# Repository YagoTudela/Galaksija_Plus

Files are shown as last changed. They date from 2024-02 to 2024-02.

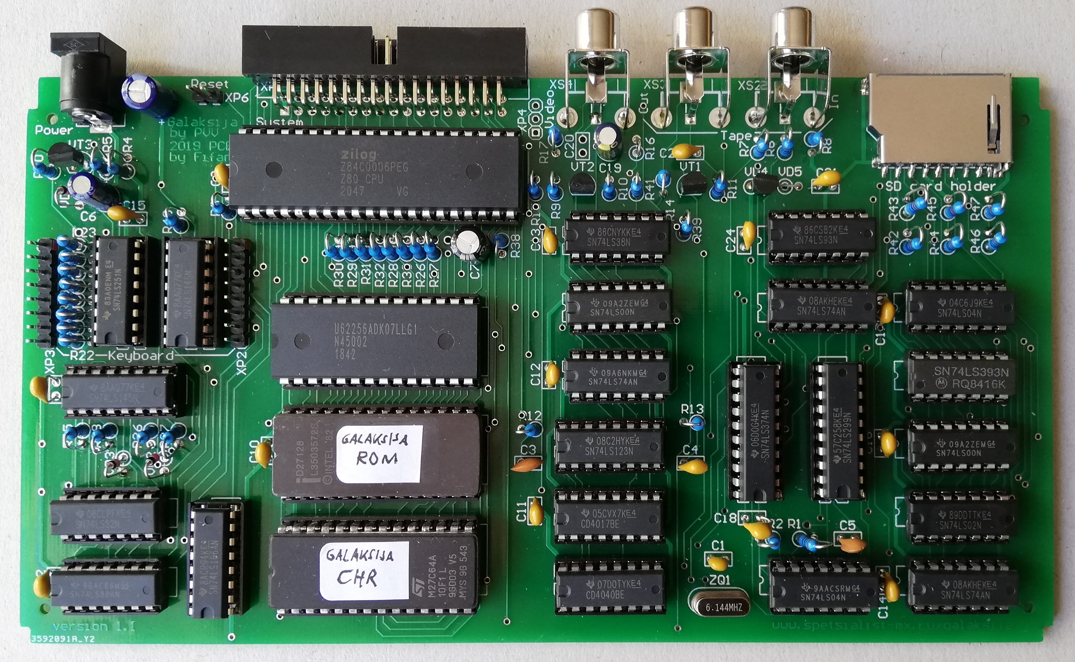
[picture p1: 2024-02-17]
GalaksijaPlusClone_BoardComplete_RetroBertie.jpg

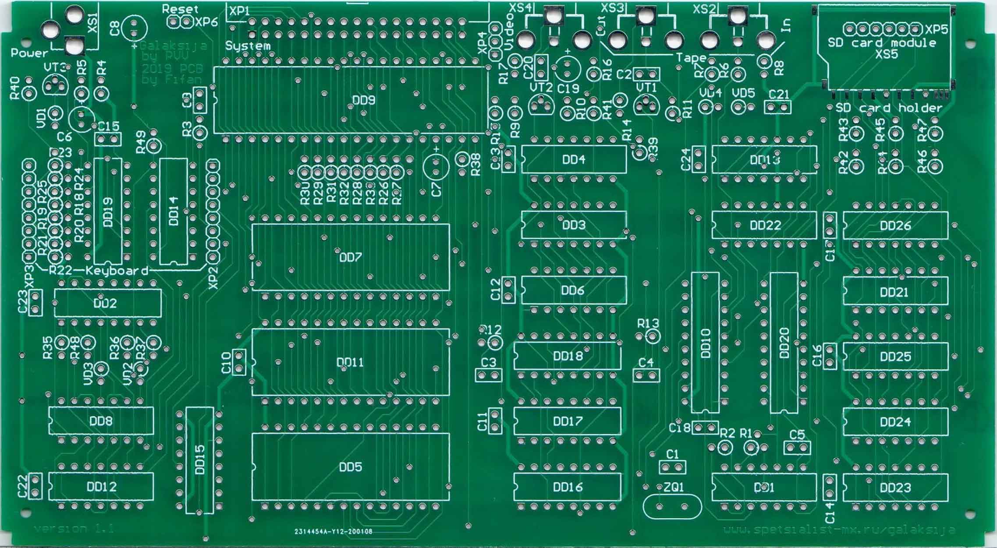
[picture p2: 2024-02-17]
GalaksijaPlusClone_BoardEmpty_YT2FSG.jpg

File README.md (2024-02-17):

# Galaksija_Plus
 GalaksijaPlus

Galaksija Plus Replica by Fifan/PVV: Assembly Guide 
by RobertK a.k.a. Retro Bertie (2022)
RetroBertie@outlook.com

https://drive.google.com/drive/folders/1J3synVV-5PiKcZs9oFsY-6CqWDRKv7X2

This is a replica of the Z80-based "Galaskija Plus" DIY computer from Yugoslavia from the 1980s.

The original files had been published on...

http://www.spetsialist-mx.ru/Galaksija/index6.html

...but this web site is no longer available, so I have put all the files online here and added a BOM, and the Gerber and Sprint Layout files for my PS/2 keyboard adapter PCB.

GalaksijaPlus_Fifan_Schematic.pdf			Scheme of Galaksija Plus clone from Fifan
galaksija_chrgen.rar					Binary file for EPROM 27C64 "CHRGEN" (DD5)
galaksija_rom_v8_6.zip					Binary file for EPROM 27C128 "ROM" (DD11)
GalaksijaPlusGerbers.rar				Gerber files for the production of PCB
PVVSDcard.rar						File archive for SD card from PVV
PVVPS2adapter.zip					File archive for PS/2 keyboard adapter from PVV
GalaksijaPlus_PVV_BOM.xls				BOM for the main board, PS/2 adapter and Sound Generator (Retro Bertie)
GalaksijaPlusClone_BoardComplete_RetroBertie.jpg	Photo of the complete board (Retro Bertie)
GalaksijaPlusClone_BoardEmpty_YT2FSG.jpg		Photo of the empty board (YT2FSG)

For writing the 27C64 EPROM DD5 ("CHRGEN"), use the file GALAXY_CHRGENP8.BIN (8K).
For the 27C128 EPROM DD11 ("ROM") use GALAXY_ROM16.BIN (16K).

The following modifications should be done (they are already included in the BOM):

1. Video Output
Video Components are: VT2, R16, R17, C19, C20
R16 = 0 (connect directly)
R17 = 220R
C19 = 4.7uF
Do not mount C20

2. SD Card
Instead of VD4 and VD5, use a 78L33 (3.3V) voltage stabilizer
Left Pin = Input, Centre Pin = GND, Right pin = Output

3. Power Supply for the Main Board
It is recommended to use a laboratory PSU, start at 5V and reduce the voltage until the picture gets stable.
The picture should get stable when the voltage is reduced to 4.35 Volts.
If you don't have a laboratory PSU, you can use a 5V mobile phone charger, reduce the voltage using a 1N4007 diode. If the resulting voltage should be too low, use two Schottky diodes (e.g. 1N5817 or 1N5819) instead.
Connect XP2 Pin 1 (the rightmost pin) with DD14 Pin 8 (GND), this will connect ground between the main board and the PS/2 adapter. With this modification, the keyboard will work with separate power supplies too.

4. The correct values for the resistors R11 and R14 are:
R11 100
R14 2,4K
In the schematic, their values are swapped, with the result that loading from the audio input would not work.

Here is a Youtube video showing my building process:
https://youtu.be/Uxc2ua1hdcY

=== SOURCES / REFERENCES ===

http://www.spetsialist-mx.ru/Galaksija/
The repository for the main board Gerber files, ROM images and Schematic. Now offline, an archived version can be accessed here:
https://web.archive.org/web/20210123223417/http://www.spetsialist-mx.ru/Galaksija/index6.html

http://emulator.galaksija.org/MagScans/index.html
The magazine scans shown in the beginning of my video were downloaded from there.

https://www.youtube.com/watch?v=NPDcvZwGBMA&t=24s
Youtube video "Voja Antonic o igrama na Galaksiji", the photo of Mr. Antonic was taken from there.

https://www.qsl.net/yt2fsg/galaksija/galaksija_clone.html
Goran's Galaksija Clone, the photo of the empty board was taken from there.

=== OTHER LINKS ===

http://retrospec.sgn.net/users/tomcat/yu/Galaksija_list.php
Software Archive

http://galaksija.epizy.com/Help/Tape/
Another software Archive on galaksija.epizy.com

https://github.com/z88dk/z88dk/wiki/Platform---Galaksija
z88dk C compiler supporting the Galaksija system (among many other machines)

https://blog.vladovince.com/building-a-galaksija-the-1980s-yugoslav-8-bit-microcomputer-part-i-the-tech/
https://github.com/mejs/galaksija
Building the original Galaksija computer

https://oldcomputer.info/8bit/galaksija/index.htm
Another person who has built the original Galaksija

https://www.apuliaretrocomputing.it/wordpress/?p=4234
One more original Galaksija built

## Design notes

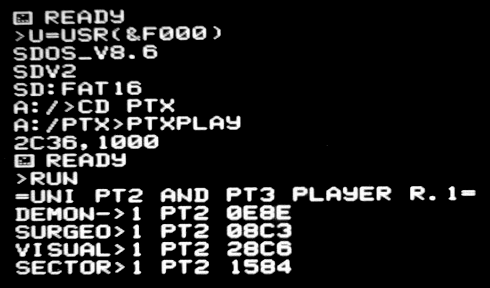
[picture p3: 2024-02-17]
SoundGenerator/SoundGeneratorPVV_03.png

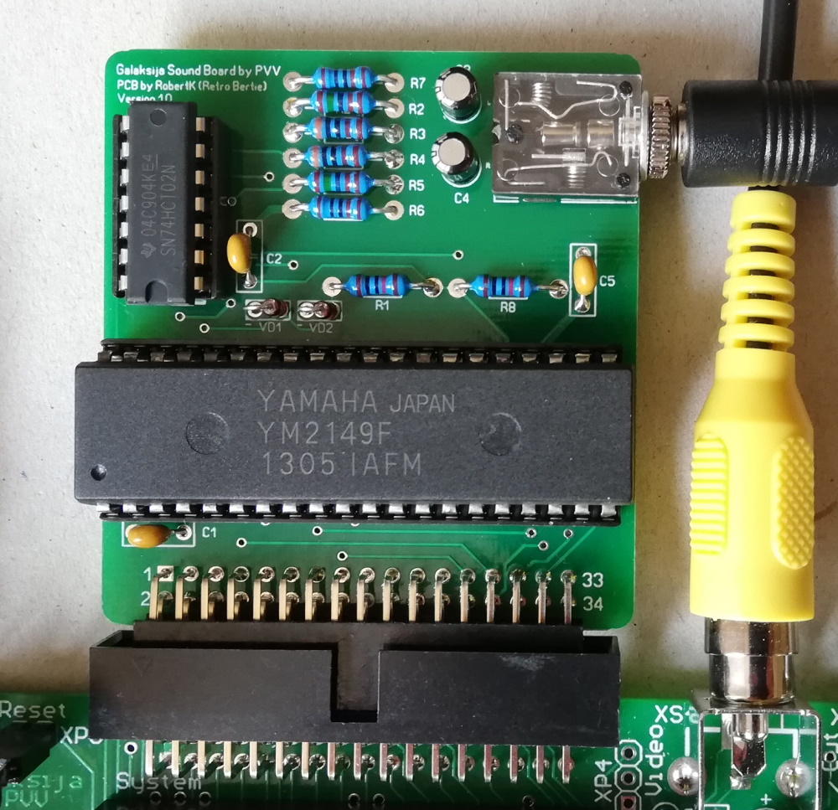
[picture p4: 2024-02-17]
SoundGenerator/GalaksijaSound_v10_RetroBertie.JPG

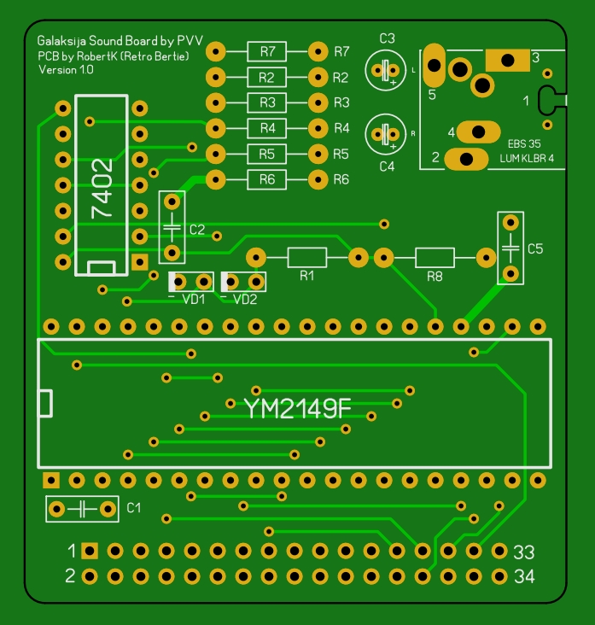
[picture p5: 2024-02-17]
SoundGenerator/GalaksijaSound_v10.JPG

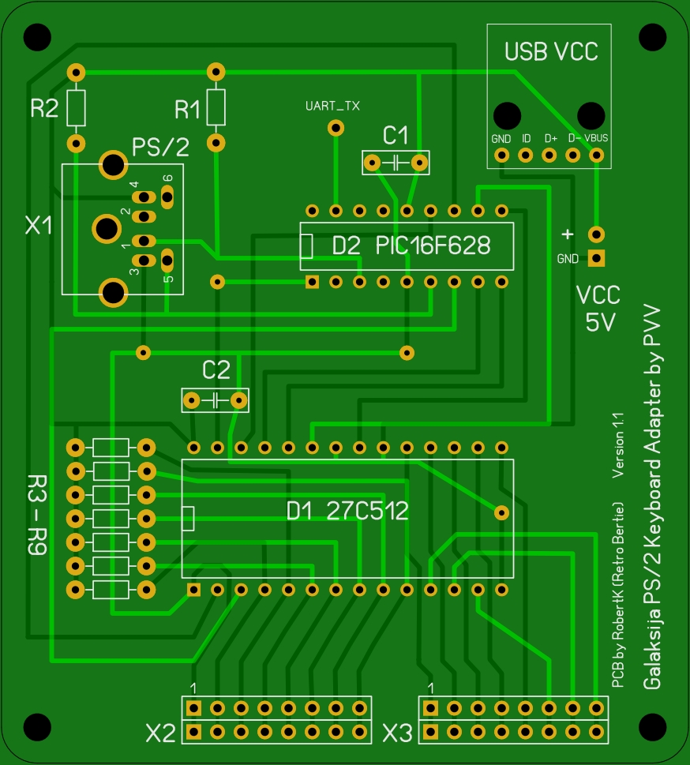
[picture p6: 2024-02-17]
PS2_Adapter/GalaksijaPS2_v11a.JPG

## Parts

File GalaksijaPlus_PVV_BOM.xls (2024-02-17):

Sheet: Galaksija Plus Board
Part | Type | Purpose | Note | Quantity | Mouser | Reichelt | Conrad | Restore Store | Amazon | Value in Fifan's Schematic | Price excl. VAT | Price incl. VAT | Price total
DD1 | 74LS04 |  |  | 2 | 595-SN74LS04N |  |  |  |  |  | €0.70 | €0.84 | €1.69
DD2 | 74LS145 |  |  | 2 | 595-SN74LS145N |  |  |  |  |  | €1.07 | €1.28 | €2.57
DD3 | 74LS00 |  |  | 2 | 595-SN74LS00N |  |  |  |  |  | €0.60 | €0.72 | €1.44
DD4 | 74LS38 |  |  | 1 | 595-SN74LS38N |  |  |  |  |  | €0.87 | €1.05 | €1.05
DD5 | 27C64 | EPROM 8K | Ebay | 1 |  |  |  | EPR-C064 |  |  |  | €2.00 | €2.00
DD6 | 74LS74 |  |  | 3 | SN74LS74AN |  |  |  |  |  | €0.59 | €0.71 | €2.13
DD7 | 62256 |  | Mouser: End of Life Product | 1 | U62256ADK07LLG1 | 62256-80 |  |  |  |  | €4.35 | €5.22 | €5.22
DD8 | 74LS32 |  |  | 1 | SN74LS32N |  |  |  |  |  | €0.59 | €0.71 | €0.71
DD9 | Z80 | CPU |  | 1 | Z84C0006PEG |  |  |  |  |  | €5.42 | €6.50 | €6.50
DD10 | 74LS374 |  |  | 1 | SN74LS374N |  |  |  |  |  | €0.79 | €0.95 | €0.95
DD11 | 27C128 | EPROM 16K | Ebay | 1 |  |  |  | EPR-C128 |  |  |  | €2.00 | €2.00
DD12 | 74LS86 |  |  | 1 | SN74LS86AN |  |  |  |  |  | €0.59 | €0.71 | €0.71
DD13 | 74LS93 |  |  | 1 | SN74LS93N |  |  |  |  |  | €2.19 | €2.63 | €2.63
DD14 | 74LS145 |  |  | see above | see above |  |  |  |  |  | €0.00 | €0.00 | €0.00
DD15 | 74LS166 |  |  | 1 | SN74LS166AN |  |  |  |  |  | €0.99 | €1.19 | €1.19
DD16 | CD4040 |  |  | 1 | CD4040BE | CD 4040BE TEX |  |  |  |  |  | €0.57 | €0.57
DD17 | CD4017 |  |  | 1 | CD4017BE |  |  |  |  |  | €0.52 | €0.62 | €0.62
DD18 | 74LS123 |  |  | 1 | SN74LS123N |  |  |  |  |  | €0.81 | €0.97 | €0.97
DD19 | 74LS251 |  |  | 1 | SN74LS251N |  |  |  |  |  | €0.81 | €0.97 | €0.97
DD20 | 74LS299 |  |  | 1 | SN74LS299N |  |  |  |  |  | €3.57 | €4.28 | €4.28
DD21 | 74LS393 |  |  | 1 | SN74LS393N | LS 393 |  |  |  |  |  | €0.60 | €0.60
DD22 | 74LS74 |  |  | see above | see above |  |  |  |  |  | €0.00 | €0.00 | €0.00
DD23 | 74LS74 |  |  | see above | see above |  |  |  |  |  | €0.00 | €0.00 | €0.00
DD24 | 74LS02 |  |  | 1 | SN74LS02N |  |  |  |  |  | €0.63 | €0.75 | €0.75
DD25 | 74LS00 |  |  | see above | see above |  |  |  |  |  | €0.00 | €0.00 | €0.00
DD26 | 74LS04 |  |  | see above | see above |  |  |  |  |  | €0.00 | €0.00 | €0.00
C1 | 4700pF = 4,7nF (472) |  |  | 1 |  | KERKO 4,7N |  |  |  | 4700 |  | €0.05 | €0.05
C2 | 0,1uF = 100nF (104) |  |  | 16 |  | KERKO 100N |  |  |  | 0,1 МК |  | €0.07 | €1.12
C3 | 0,022uF = 22nF (223) | Audio Input/Output |  | 1 |  | KERKO 22N |  |  |  | 0,022 МК |  | €0.06 | €0.06
C4 | 0,1uF = 100nF (104) |  |  | see above |  | see above |  |  |  | 0,1 МК | €0.00 | €0.00 | €0.00
C5 | 47pF (47) |  |  | 1 |  | KERKO 47P |  |  |  | 47 |  | €0.05 | €0.05
C6 | 22uF 10V |  | 10V or more | 1 |  | FC-A 22U 35 | 441999 - U3 |  |  | 22 МК 10 В |  | €0.13 | €0.13
C7 | 1uF 10V |  | 10V or more | 1 |  | RND 150EHR91992 | 1471210 - U3 |  |  | 1 МК 10 В |  | €0.29 | €0.29
C8 | 47uF 16V |  |  | 1 |  | FM-A 47U 25 | 442022 - U3 |  |  | 47 МК |  | €0.12 | €0.12
C9 | 0,1uF = 100nF (104) |  | near R3 | see above |  | see above |  |  |  | 0,1 МК | €0.00 | €0.00 | €0.00
C10 | 0,1uF = 100nF (104) |  |  | see above |  | see above |  |  |  | 0,1 МК | €0.00 | €0.00 | €0.00
C11 | 0,1uF = 100nF (104) |  |  | see above |  | see above |  |  |  | 0,1 МК | €0.00 | €0.00 | €0.00
C12 | 0,1uF = 100nF (104) |  |  | see above |  | see above |  |  |  | 0,1 МК | €0.00 | €0.00 | €0.00
C13 | 0,1uF = 100nF (104) |  |  | see above |  | see above |  |  |  | 0,1 МК | €0.00 | €0.00 | €0.00
C14 | 0,1uF = 100nF (104) |  |  | see above |  | see above |  |  |  | 0,1 МК | €0.00 | €0.00 | €0.00
C15 | 0,1uF = 100nF (104) |  |  | see above |  | see above |  |  |  | 0,1 МК | €0.00 | €0.00 | €0.00
C16 | 0,1uF = 100nF (104) |  |  | see above |  | see above |  |  |  | 0,1 МК | €0.00 | €0.00 | €0.00
C17 | 0,1uF = 100nF (104) |  |  | see above |  | see above |  |  |  | 0,1 МК | €0.00 | €0.00 | €0.00
C18 | 0,1uF = 100nF (104) |  |  | see above |  | see above |  |  |  | 0,1 МК | €0.00 | €0.00 | €0.00
C19 | 470uF 10V | Video Output | 10V or more; initially 4,7uF, but this gave picture problems when the screen was predominantly white | 1 |  | RAD FC 470/10 | 1471110 - 62 |  |  | 4,7 МК 10 В |  | €0.26 | €0.26
C20 | 0,47uF = 470nF (474) | Video Output | Do not mount | NN |  |  |  |  |  | 0,47 МК | €0.00 | €0.00 | €0.00
C21 | 0,1uF = 100nF (104) |  |  | see above |  | see above |  |  |  | 0,1 МК | €0.00 | €0.00 | €0.00
C22 | 0,1uF = 100nF (104) |  |  | see above |  | see above |  |  |  | 0,1 МК | €0.00 | €0.00 | €0.00
C23 | 0,1uF = 100nF (104) |  |  | see above |  | see above |  |  |  | 0,1 МК | €0.00 | €0.00 | €0.00
C24 | 0,1uF = 100nF (104) |  |  | see above |  | see above |  |  |  | 0,1 МК | €0.00 | €0.00 | €0.00
R1 | 1K |  |  | 9 |  | METALL 1,00K |  |  |  |  |  | €0.08 | €0.72
R2 | 1K |  |  | see above |  | see above |  |  |  |  | €0.00 | €0.00 | €0.00
R3 | 1K |  |  | see above |  | see above |  |  |  |  | €0.00 | €0.00 | €0.00
R4 | 18K |  |  | 2 |  | METALL 18,0K | 1417585 - 62 |  |  |  |  | €0.15 | €0.30
R5 | 18K |  |  | see above |  | see above | see above |  |  |  | €0.00 | €0.00 | €0.00
R6 | 10K | Audio Input/Output |  | 21 |  | METALL 10,0K |  |  |  |  |  | €0.02 | €0.42
R7 | 10K | Audio Input/Output |  | see above |  | see above |  |  |  |  | €0.00 | €0.00 | €0.00
R8 | 10K | Audio Input/Output |  | see above |  | see above |  |  |  |  | €0.00 | €0.00 | €0.00
R9 | 2K |  |  | 5 |  | METALL 2,00K |  |  |  |  |  | €0.08 | €0.40
R10 | 1K |  |  | see above |  | see above |  |  |  |  | €0.00 | €0.00 | €0.00
R11 | 100 | Audio Input/Output | The values of R11 and R14 were erroneously swapped in the initial Galaksija schematic, and Fifan's schematic also had this error | 1 |  | METALL 100 |  |  |  |  |  | €0.08 | €0.08
R12 | 390 |  |  | 1 |  | METALL 390 |  |  |  |  |  | €0.08 | €0.08
R13 | 27K |  |  | 1 |  | METALL 27,0K |  |  |  |  |  | €0.08 | €0.08
R14 | 2,4K |  | The values of R11 and R14 were erroneously swapped in the initial Galaksija schematic, and Fifan's schematic also had this error | 1 |  | METALL 2,40K |  |  |  |  |  | €0.08 | €0.08
R15 | 4,7K |  | near C13 | 4 |  | METALL 4,70K |  |  |  |  |  | €0.08 | €0.32
R16 | 100 | Video Output | Connect directly (0 Ω) | NN |  |  |  |  |  |  | €0.00 | €0.00 | €0.00
R17 | 220 | Video Output | Originally 51 Ω, use 220 Ω instead | 1 |  | METALL 220 | 1417626 - U3 |  |  |  |  | €0.15 | €0.15
R18 | 10K |  |  | see above |  | see above |  |  |  |  | €0.00 | €0.00 | €0.00
R19 | 10K |  |  | see above |  | see above |  |  |  |  | €0.00 | €0.00 | €0.00
R20 | 10K |  |  | see above |  | see above |  |  |  |  | €0.00 | €0.00 | €0.00
R21 | 10K |  |  | see above |  | see above |  |  |  |  | €0.00 | €0.00 | €0.00
R22 | 10K |  |  | see above |  | see above |  |  |  |  | €0.00 | €0.00 | €0.00
R23 | 10K |  |  | see above |  | see above |  |  |  |  | €0.00 | €0.00 | €0.00
R24 | 10K |  |  | see above |  | see above |  |  |  |  | €0.00 | €0.00 | €0.00
R25 | 10K |  |  | see above |  | see above |  |  |  |  | €0.00 | €0.00 | €0.00
R26 | 10K |  |  | see above |  | see above |  |  |  |  | €0.00 | €0.00 | €0.00
R27 | 10K |  |  | see above |  | see above |  |  |  |  | €0.00 | €0.00 | €0.00
R28 | 10K |  |  | see above |  | see above |  |  |  |  | €0.00 | €0.00 | €0.00
R29 | 10K |  |  | see above |  | see above |  |  |  |  | €0.00 | €0.00 | €0.00
R30 | 10K |  |  | see above |  | see above |  |  |  |  | €0.00 | €0.00 | €0.00
R31 | 10K |  |  | see above |  | see above |  |  |  |  | €0.00 | €0.00 | €0.00
R32 | 10K |  |  | see above |  | see above |  |  |  |  | €0.00 | €0.00 | €0.00
R33 | 10K |  |  | see above |  | see above |  |  |  |  | €0.00 | €0.00 | €0.00
R35 | 1K |  | There is no R34 | see above |  | see above |  |  |  |  | €0.00 | €0.00 | €0.00
R36 | 1K |  |  | see above |  | see above |  |  |  |  | €0.00 | €0.00 | €0.00
R37 | 2K |  |  | see above |  | see above |  |  |  |  | €0.00 | €0.00 | €0.00
R38 | 1K |  |  | see above |  | see above |  |  |  |  | €0.00 | €0.00 | €0.00
R39 | 3K |  |  | 1 |  | METALL 3,00K |  |  |  |  |  | €0.08 | €0.08
R40 | 10K |  |  | see above |  | see above |  |  |  |  | €0.00 | €0.00 | €0.00
R41 | 1K | Audio Input/Output |  | see above |  | see above |  |  |  |  | €0.00 | €0.00 | €0.00
R42 | 2K |  |  | see above |  | see above |  |  |  |  | €0.00 | €0.00 | €0.00
R43 | 4,7K |  |  | see above |  | see above |  |  |  |  | €0.00 | €0.00 | €0.00
R44 | 2K |  |  | see above |  | see above |  |  |  |  | €0.00 | €0.00 | €0.00
R45 | 4,7K |  |  | see above |  | see above |  |  |  |  | €0.00 | €0.00 | €0.00
R46 | 2K |  |  | see above |  | see above |  |  |  |  | €0.00 | €0.00 | €0.00
R47 | 4,7K |  |  | see above |  | see above |  |  |  |  | €0.00 | €0.00 | €0.00
R48 | 1K |  |  | see above |  | see above |  |  |  |  | €0.00 | €0.00 | €0.00
R49 | 10K |  |  | see above |  | see above |  |  |  |  | €0.00 | €0.00 | €0.00
VD1 | 1N4148 |  |  | 3 |  | 1N 4148 |  |  |  |  |  | €0.02 | €0.06
VD2 | 1N4148 |  |  | see above |  | see above |  |  |  |  | €0.00 | €0.00 | €0.00
VD3 | 1N4148 |  |  | see above |  | see above |  |  |  |  | €0.00 | €0.00 | €0.00
VD4 | 1N4148 |  | Use a 78L33 (3.3V) voltage stabilizer instead | NN |  |  |  |  |  |  | €0.00 | €0.00 | €0.00
VD5 | 1N4148 |  | see VD4 | NN |  |  |  |  |  |  | €0.00 | €0.00 | €0.00
VT1 | BC547 | Audio Input/Output | BC 547A, 547B or 547C will all work | 3 |  | BC 547C | 140539 - U3 |  |  |  |  | €0.03 | €0.09
VT2 | BC547 | Video Output |  | see above |  | see above |  |  |  |  | €0.00 | €0.00 | €0.00
VT3 | BC547 |  |  | see above |  | see above |  |  |  |  | €0.00 | €0.00 | €0.00
ZQ1 | 6,144 МHz | Quartz |  | 1 |  | 6,1440-HC49U-S |  |  |  |  |  | €0.22 | €0.22
XP1 | Box Connector 34-pin | Expansion Port |  | 1 |  | WSL 34W | 1498242 - U3 |  |  |  |  | €0.27 | €0.27
XP2 | 8 Pin | Pin Headers | Keyboard Connector | 1 |  | SL 1X40G 2,54 | 1560960 - ES |  |  |  |  | €0.25 | €0.25
XP3 | 8 Pin | Pin Headers | Keyboard Connector | see above |  | see above |  |  |  |  | €0.00 | €0.00 | €0.00
XP4 | 3 Pin | Pin Headers | not required | see above |  | see above |  |  |  |  | €0.00 | €0.00 | €0.00
XP5 | SD Card Slot |  |  | 1 | 710-693063020911 |  |  |  |  |  | €2.88 | €3.46 | €3.46
XP6 | Reset Button |  | Miniature Push Button, solder to a 2x Female Socket Strip (Conrad 1498257 - U3). Not very stable, try to find a better solution. | 1 |  | T 250A RT |  |  |  |  |  | €0.54 | €0.54
XS1 | DC Socket |  | Power Supply Connector | 1 |  | DC BU21 90 |  |  |  |  |  | €0.49 | €0.49
XS2 | RCA Connector | Tape In |  | 3 |  | CBP |  |  |  |  |  | €0.24 | €0.72
XS3 | RCA Connector | Tape Out |  | see above |  | see above |  |  |  |  | €0.00 | €0.00 | €0.00
XS4 | RCA Connector | Video Output |  | see above |  | see above |  |  |  |  | €0.00 | €0.00 | €0.00
instead of VD4+VD5 | 78L33 (3.3V) |  | Voltage Stabilizer instead of VD4 and VD5. Left Pin = Input, Centre Pin = GND, Right Pin = Output | 1 | L78L33ACZ |  |  |  |  |  | €0.32 | €0.39 | €0.39
IC Socket 14-pin |  |  |  | 13 |  | GS 14 |  |  |  |  |  | €0.05 | €0.65
IC Socket 16-pin |  |  |  | 7 | 571-1-2199298-4 | GS 16 |  |  |  |  | €0.22 | €0.26 | €1.85
IC Socket 20-pin |  |  |  | 2 |  | GS 20 |  |  |  |  |  | €0.06 | €0.12
IC Socket 28-pin |  |  |  | 3 |  | GS 28 |  |  |  |  |  | €0.11 | €0.33
IC Socket 40-pin |  |  |  | 1 | 571-1-2199299-5 | GS 40 |  |  |  |  | €0.67 | €0.80 | €0.80
DC Cable 5.50 2.10 mm | Power Supply |  | Plus is inside, Ground outside! | 1 |  |  | 1662327 - 62 |  |  |  |  | €1.59 | €1.59
micro-USB Breakout Board | Power Supply |  |  | 1 | 485-1833 | DEBO MICROUSB 2 |  |  |  |  |  | €1.20 | €1.20
Diode 1N4007 for 5V -> 4,3V | Power Supply |  |  | 1 |  | 1N 4007 | 1581845 - ES |  |  |  |  | €0.02 | €0.02
Additional Equipment (optional):
Audio Adapter RCA to 3.5mm Mono |  | Tape Input/Output |  | 2 |  |  |  |  | InLine 99325 |  |  | €3.31 | €6.62
3.5mm Audio Adapter Stereo -> Mono |  | Tape Input/Output |  | 2 |  |  | 325121 - ES |  |  |  |  | €5.99 | €11.98

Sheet: PS2 Adapter
Part | Type | Note | Quantity | Mouser | Reichelt | Conrad | Price excl. VAT | Price incl. VAT | Price total
D1 | 27C512 | EPROM | 1 | 556-AT27C512R70PU | 27C512-100 |  | €2.12 | €2.54 | €2.54
D2 | PIC16F628 |  | 1 | 579-PIC16F62820P | PIC 16F628-20P |  |  | €3.47 | €3.47
X1 | 6-pin mini-DIN socket purple | PS/2 Keyboard Connector | 1 | 806-KMDGX-6S-BS | EB-DIOS M06V | 741797 - 62 |  | €0.98 | €0.98
R1-R9 | 10K |  | 9 |  | METALL 10,0K |  |  | €0.02 | €0.18
C1+C2 | 0.1uF |  | 2 |  | KERKO 100N |  |  | €0.07 | €0.14
D1 Socket | IC Socket 28 Pin 15,24 mm |  | 1 |  | GS 28 |  |  | €0.11 | €0.11
D2 Socket | IC Socket 18 Pin 7,62 mm |  | 1 |  | GS 18 |  |  | €0.07 | €0.07
USB VCC | micro-USB Breakout Board | Power Supply | 1 | 485-1833 | DEBO MICROUSB 2 |  |  | €1.20 | €1.20
X2, X3, VCC | Pin header angled (8 + 8 + 2 Pin) | Keyboard Connectors | 1 |  | SL 1X40W 2,54 |  |  | €0.24 | €0.24
X2, X3 | Ribbon Cable Socket 8 Pin | Keyboard Cable Sockets | 4 |  |  | 1401699 - 62 |  | €1.49 | €5.96
X2, X3 | Ribbon Cable 8-pin 2.5 mm | use 0,5m or more for each of the two cables | 1 |  |  | 607378 - 62 |  | €2.19 | €2.19

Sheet: Sound Generator
Part | Type | Note | Quantity | Mouser | Reichelt | Conrad
IC1 | YM2149F | Sound Chip; Ebay | 1
IC2 | 7402 |  | 1 | 595-SN7402N
C1 | 0,1uF = 100nF (104) |  | 3 |  | KERKO 100N
C2 | 0,1uF = 100nF (104) |  | see above |  | see above
C3 | 10 uF Elektrolyt |  | 2 |  | SM 10/16RAD | 1470991 - ES
C4 | 10 uF Elektrolyt |  | see above |  | see above | see above
C5 | 0,1uF = 100nF (104) |  | see above |  | see above
R1 | 10k |  | 2 |  | METALL 10,0K
R2 | 1.5k |  | 2 |  | METALL 1,50K
R3 | 3k |  | 2 |  | METALL 3,00K
R4 | 3k |  | see above |  | see above
R5 | 1.5k |  | see above |  | see above
R6 | 1k |  | 2 |  | METALL 1,00K
R7 | 1k |  | see above |  | see above
R8 | 10k |  | see above |  | see above
VD1 | 1N4148 |  | 2 |  | 1N4148
VD2 | 1N4148 |  | see above |  | see above
CONN PCB 17x2 |  | 34-pin female counterpart of XP1 box connector | 1 |  | 3M 85344500 PL
J1 |  | Audio output, 3.5 mm | 1 |  | EBS 35
IC-Socket 40 Pin |  |  | 1 |  | GS 40
IC-Socket 14 Pin |  |  | 1 |  | GS 14

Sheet: Price
Part | Price incl. VAT
Main Board PCB + Shipping | €3.43
Main Board Parts | €57.27
PS/2 PCB + Shipping | €0.79
PS/2 Parts | €17.08
Total | €78.57
Extra Parts (2x RCA Adapter, 2x Mono-Adapter) | €18.60
 |  | Shipping per Piece | Shipping Total
PCB Main Board per Piece | €2.23 | 1.2 | 6
PCB PS/2 per Piece | €0.51 | 0.28 | 1.4
Shipping Total | €7.42 |  | 7.4

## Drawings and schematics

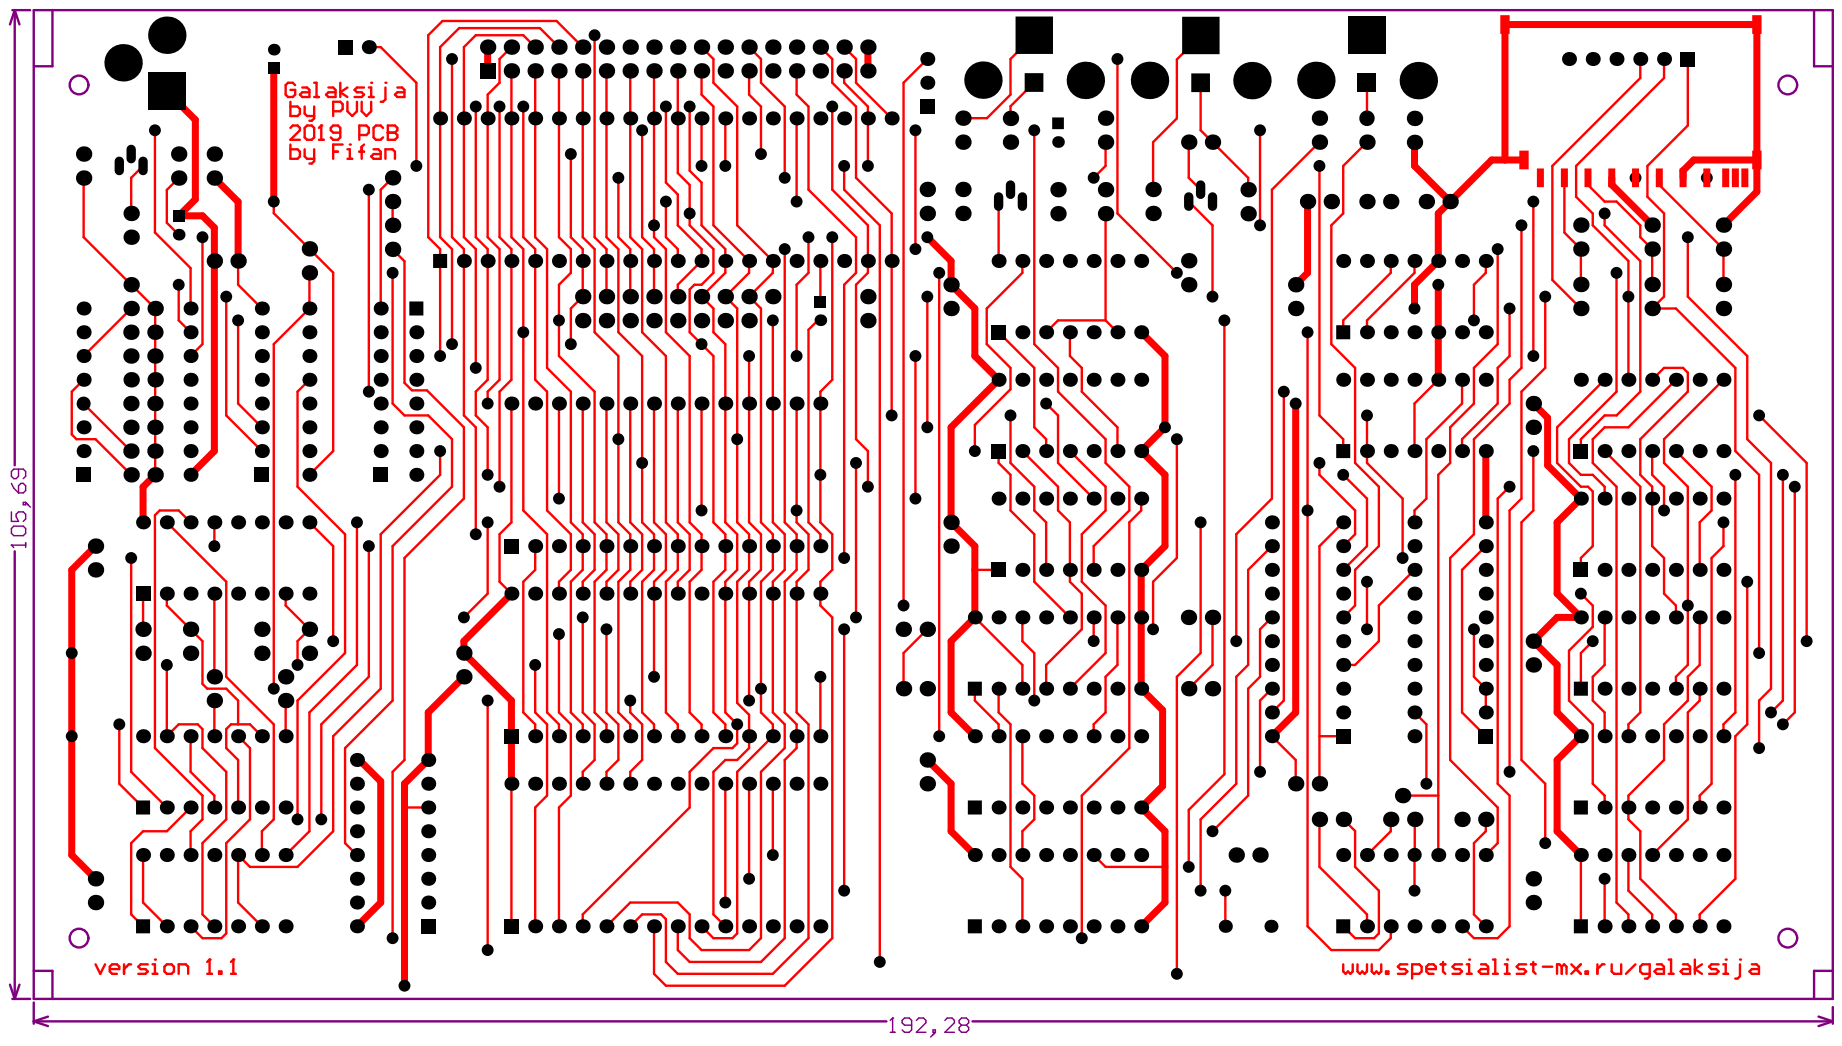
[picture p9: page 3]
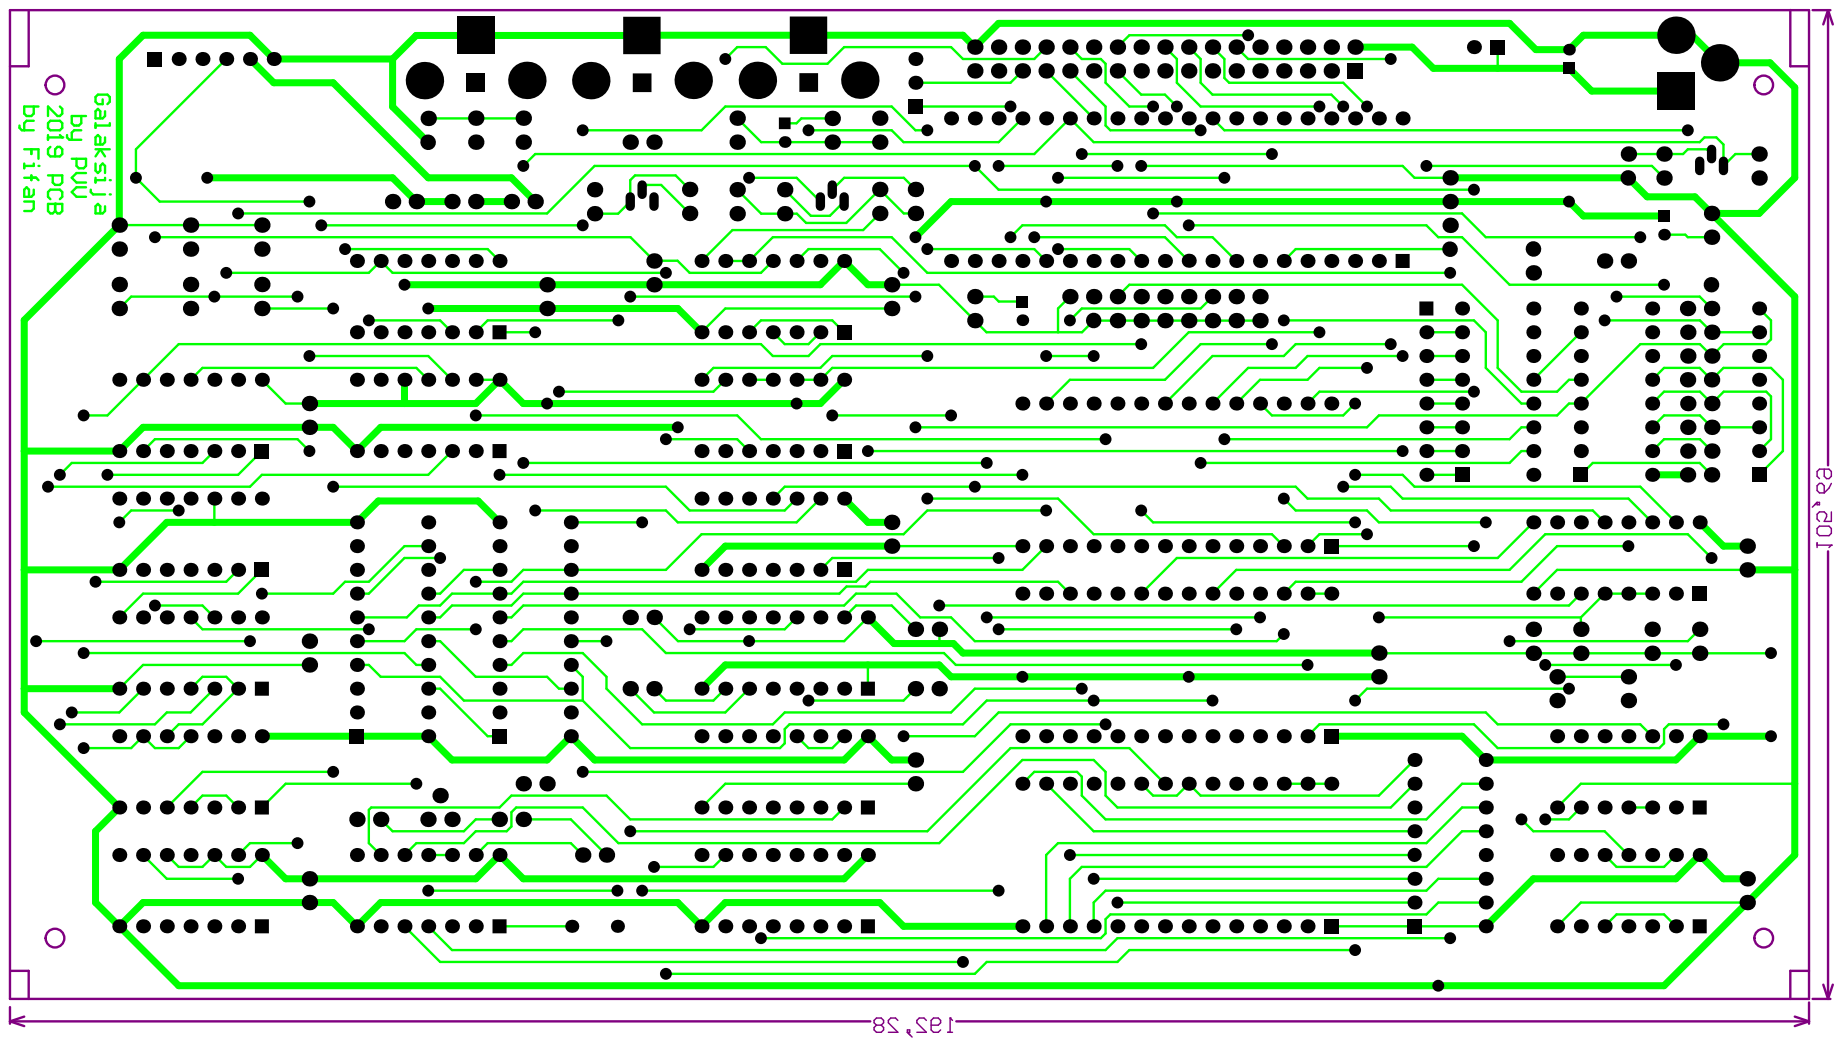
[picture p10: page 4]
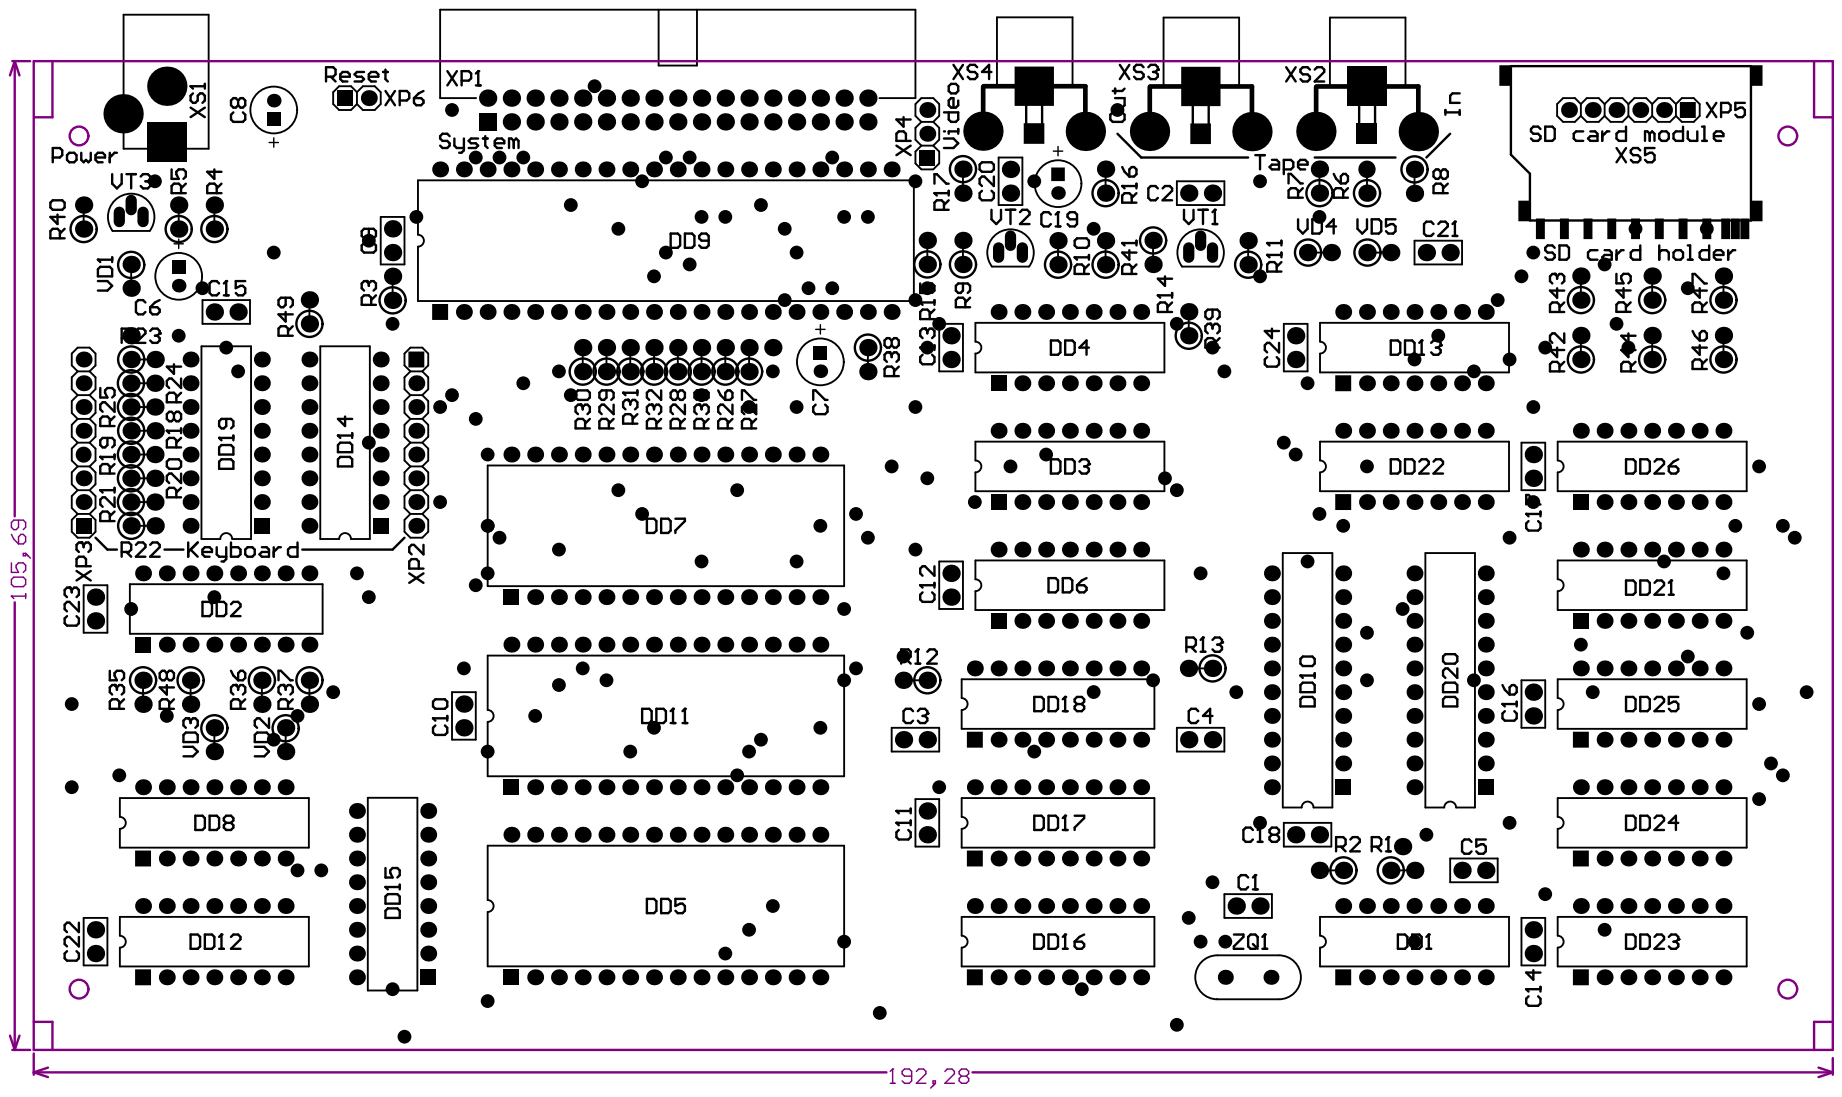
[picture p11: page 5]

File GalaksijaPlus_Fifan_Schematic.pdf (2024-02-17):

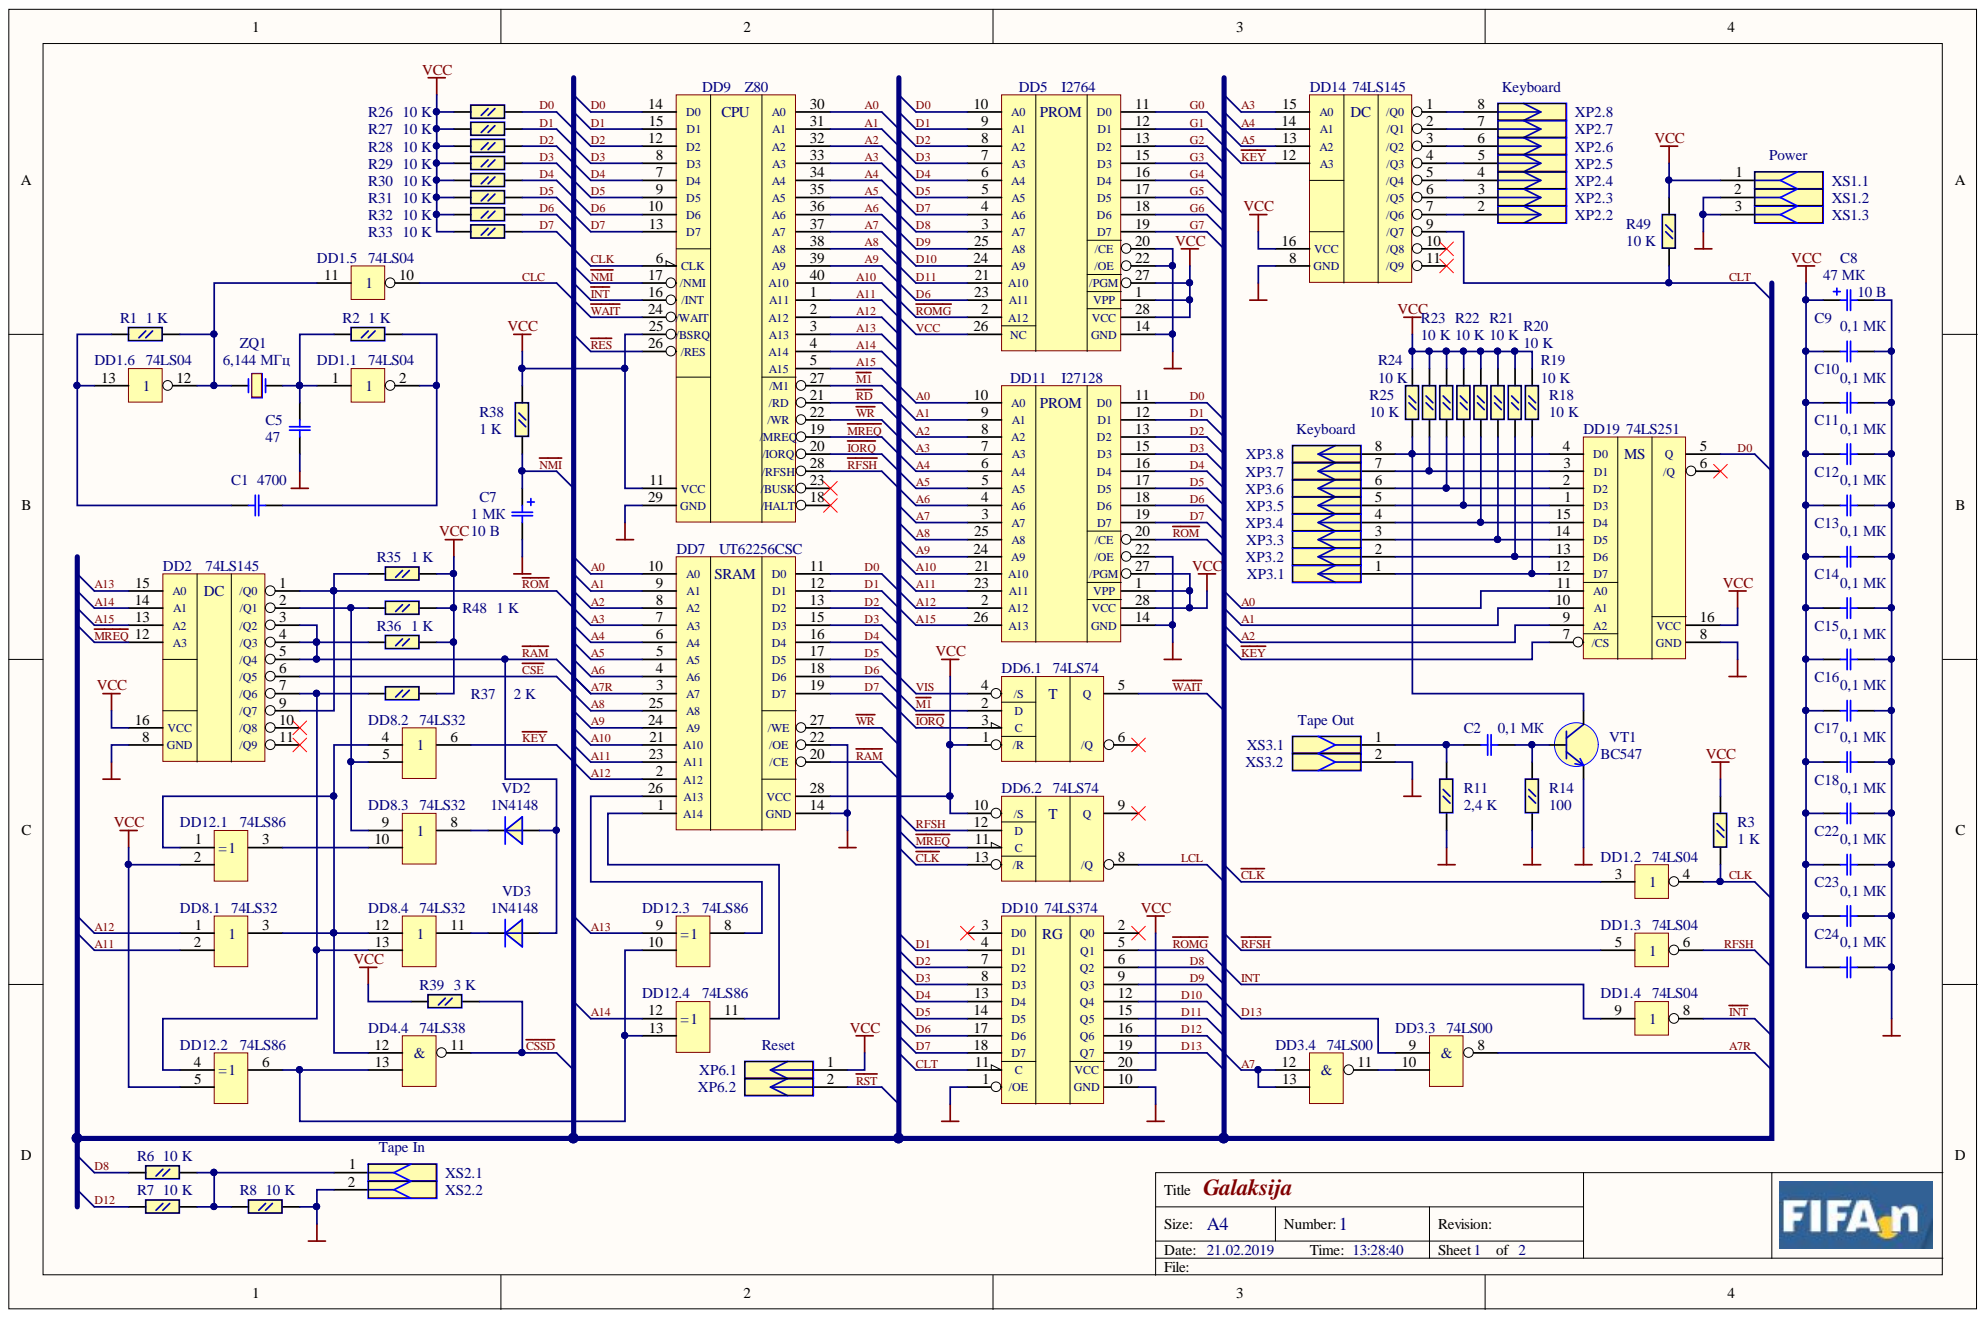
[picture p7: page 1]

Galaksija Title

A4 Size: | 1 Number: | Revision:

Date: 21.02.2019 Time: 13:28:40 | | Sheet 1 of 2

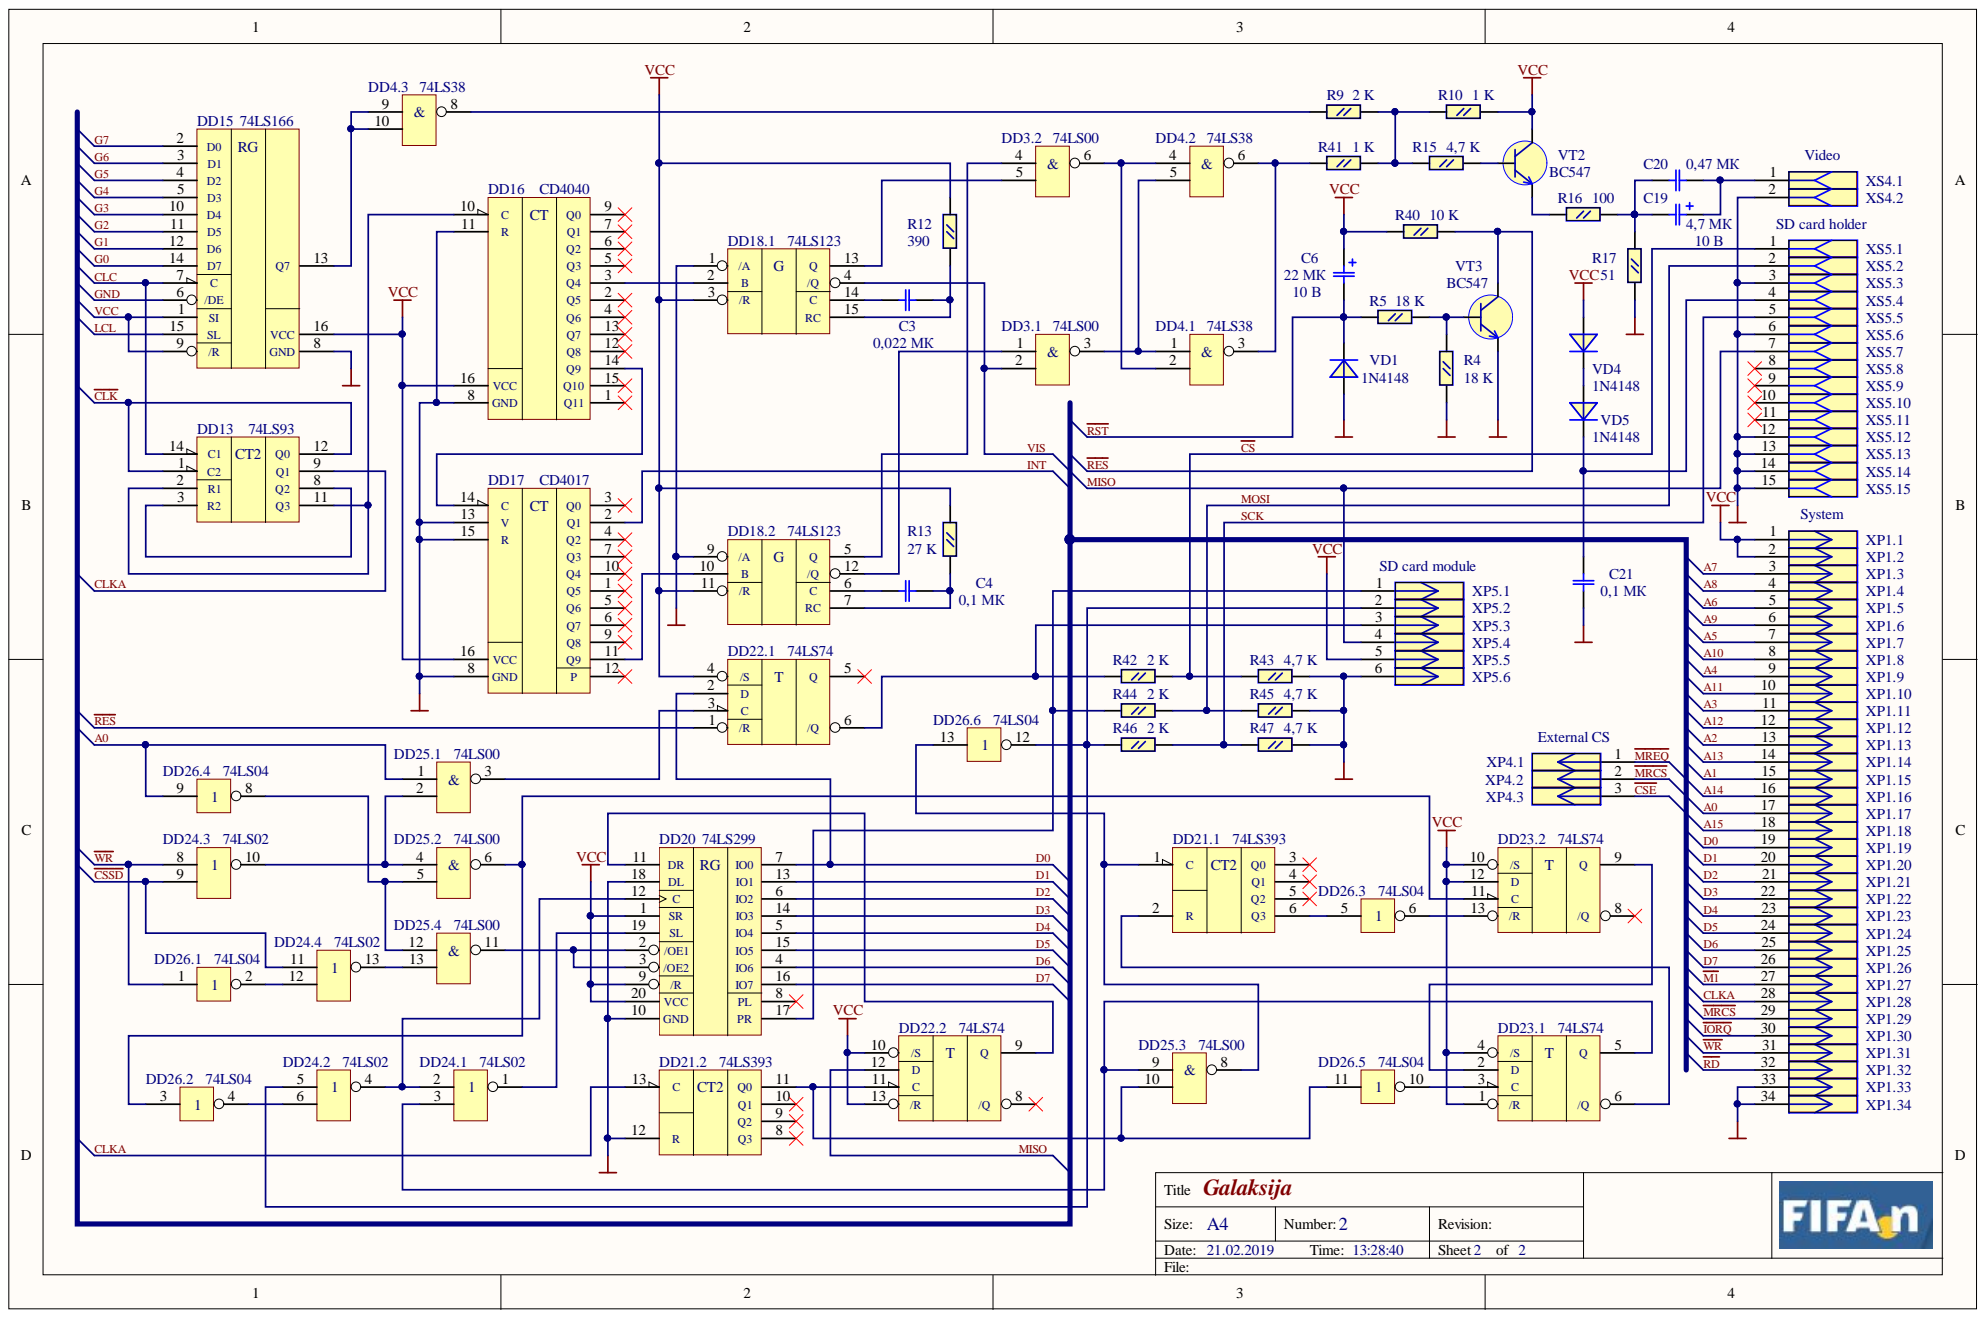
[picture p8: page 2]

VCC

20 | | | 8
VCC GND | PL

Galaksija Title

A4 Size: | 2 Number: | Revision:

Date: 21.02.2019 Time: 13:28:40 | | Sheet 2 of 2
